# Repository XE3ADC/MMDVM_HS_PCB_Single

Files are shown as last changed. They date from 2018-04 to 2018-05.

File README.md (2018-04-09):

# MMDVM_HS_PCB_Single
Single Sided PCB for MMDVM Hotspot with RF7021SE module and Blue Pill STM32DUINO

This project provides a simple, singled sided PCB for the [MMDVM_HS Hotspot main repo](https://github.com/juribeparada/MMDVM_HS). 
Can be easily made using toner transfer, has very few wires. Just order the components (RF7021SE from Aliexpress and Blue Pill 
STM32DUINO clone) and put on board. Do not forget to replace the RF7021SE standard oscillator with a supported TCXO.

Licensed under CC-BY-SA 3.0

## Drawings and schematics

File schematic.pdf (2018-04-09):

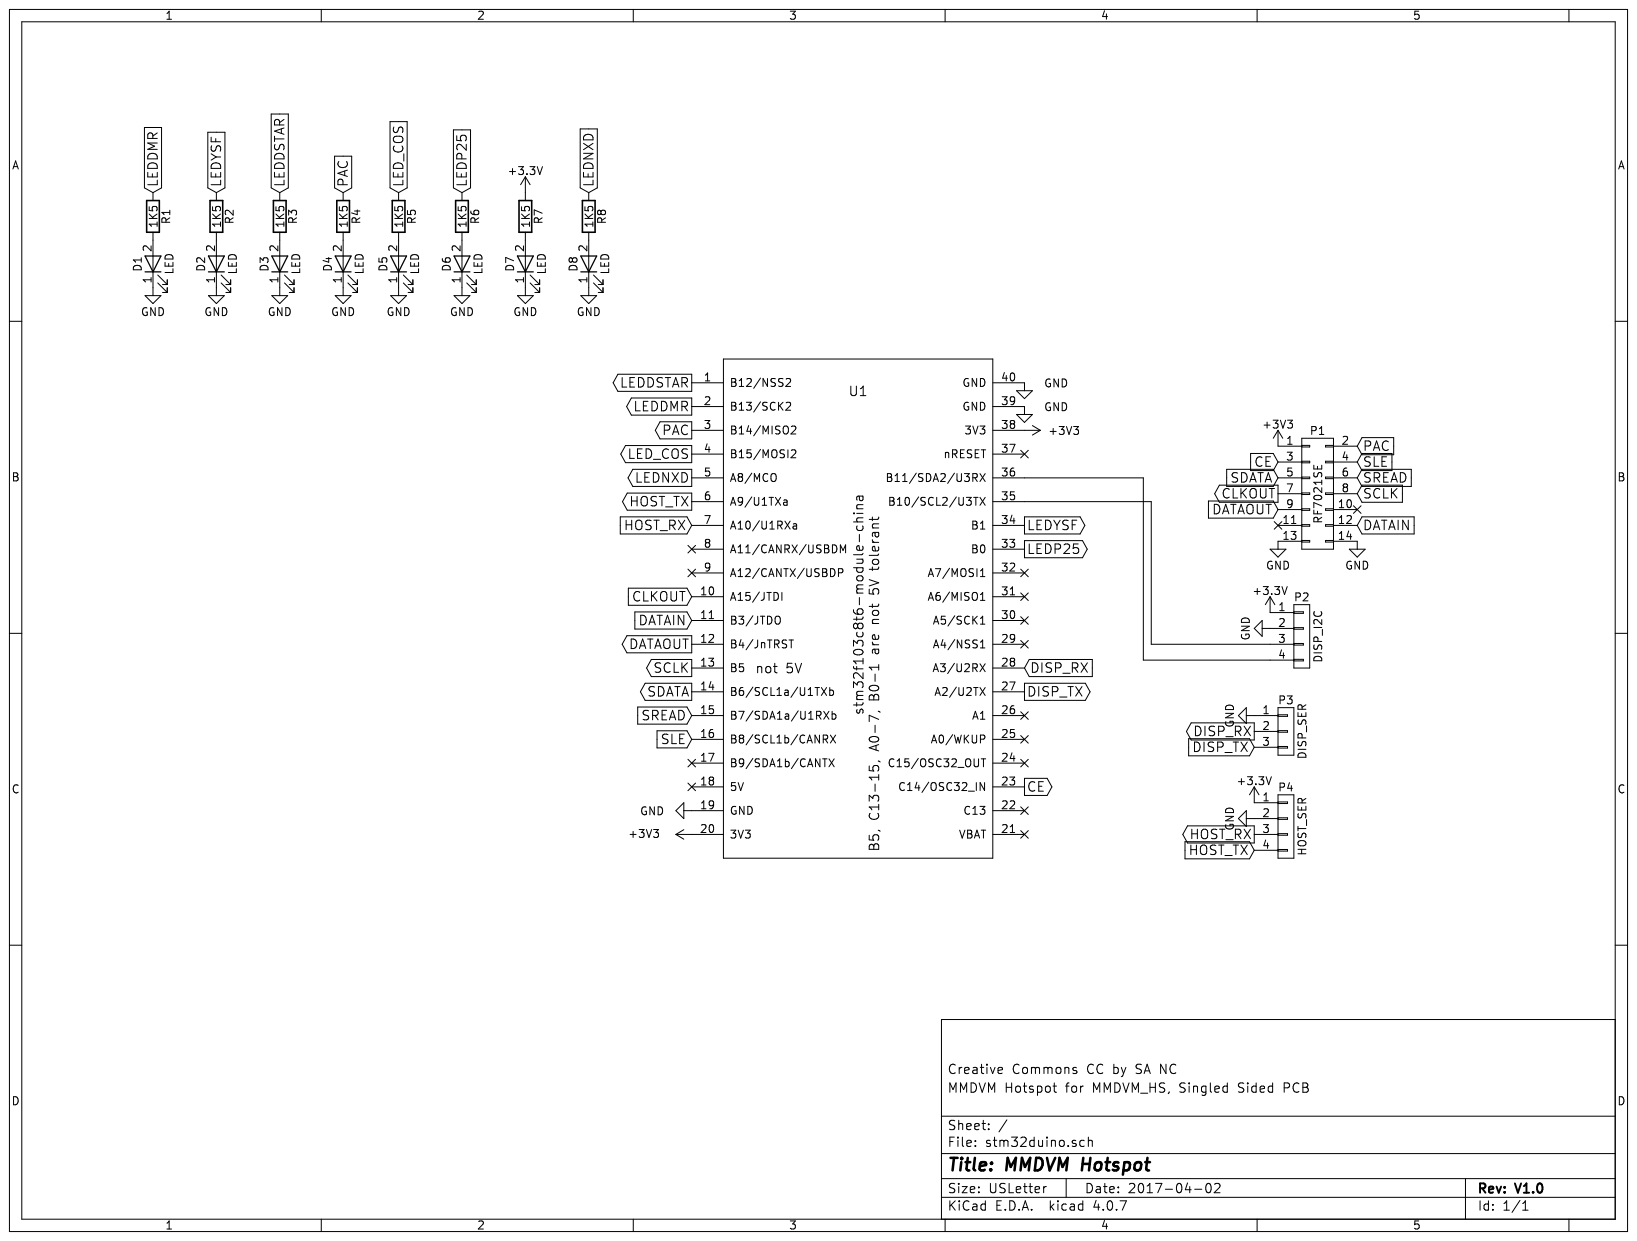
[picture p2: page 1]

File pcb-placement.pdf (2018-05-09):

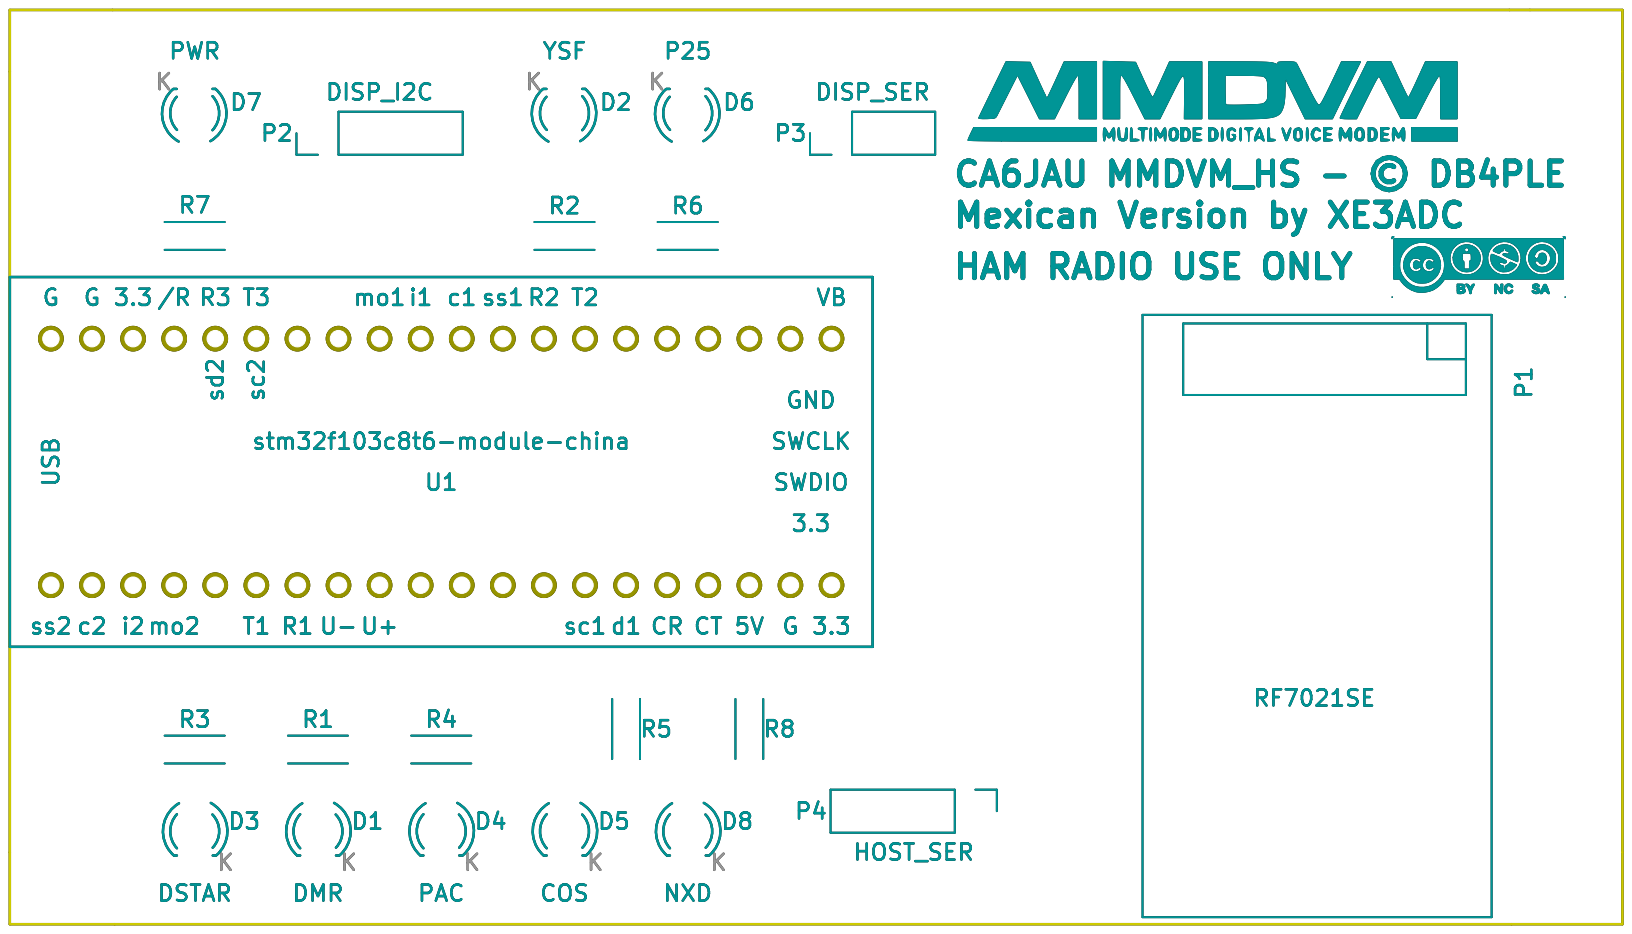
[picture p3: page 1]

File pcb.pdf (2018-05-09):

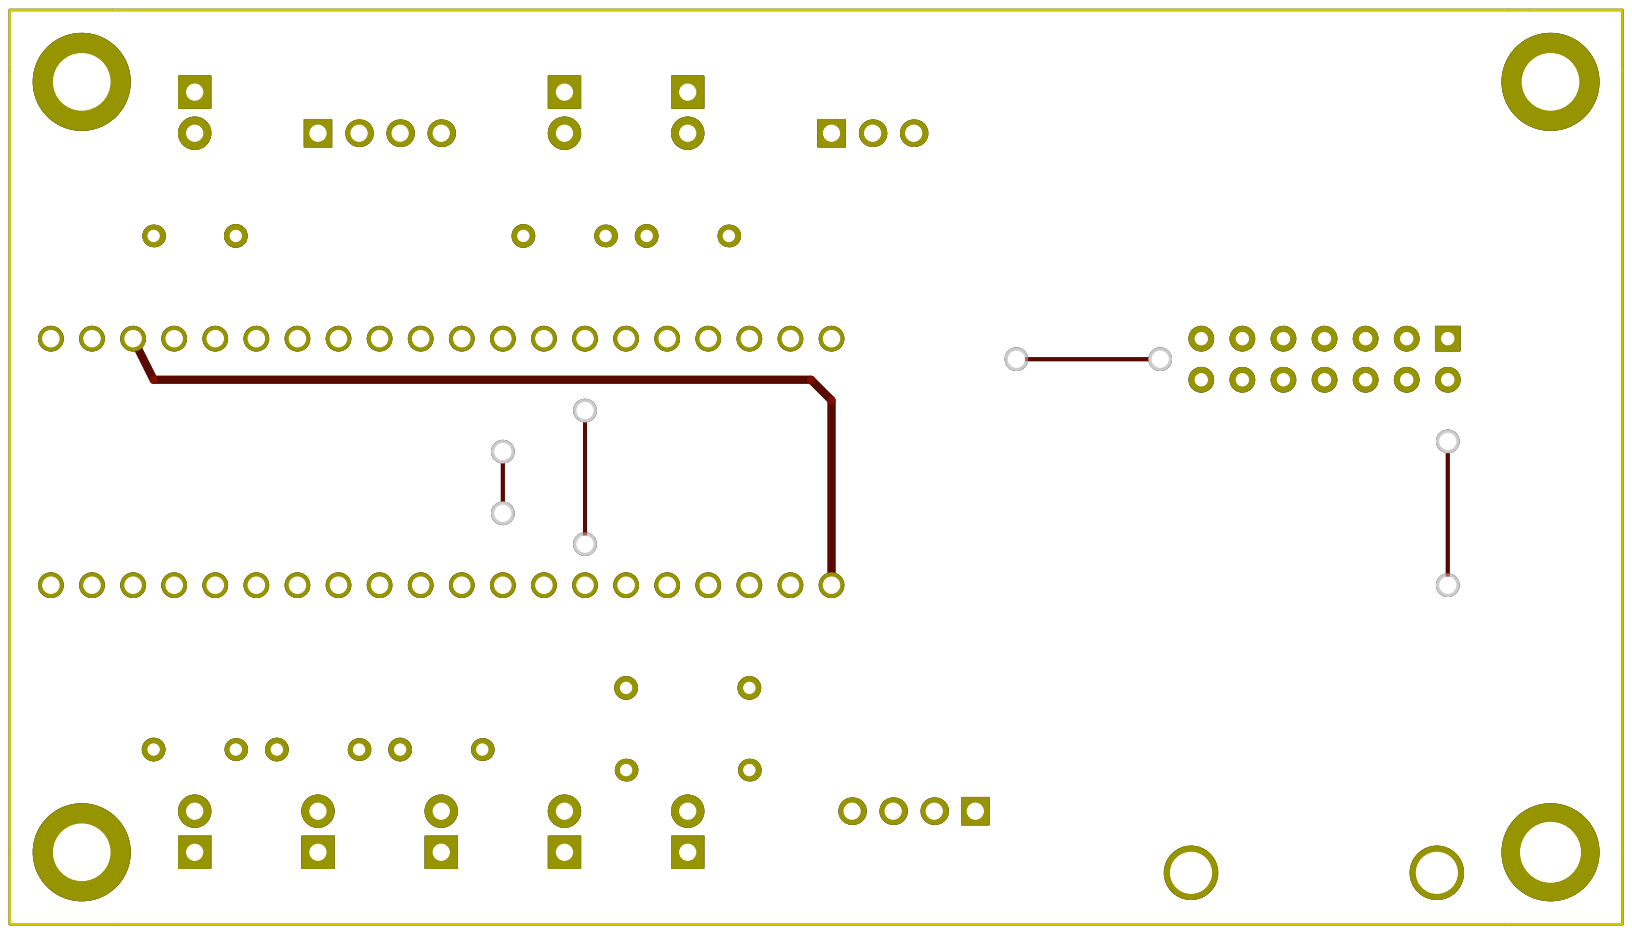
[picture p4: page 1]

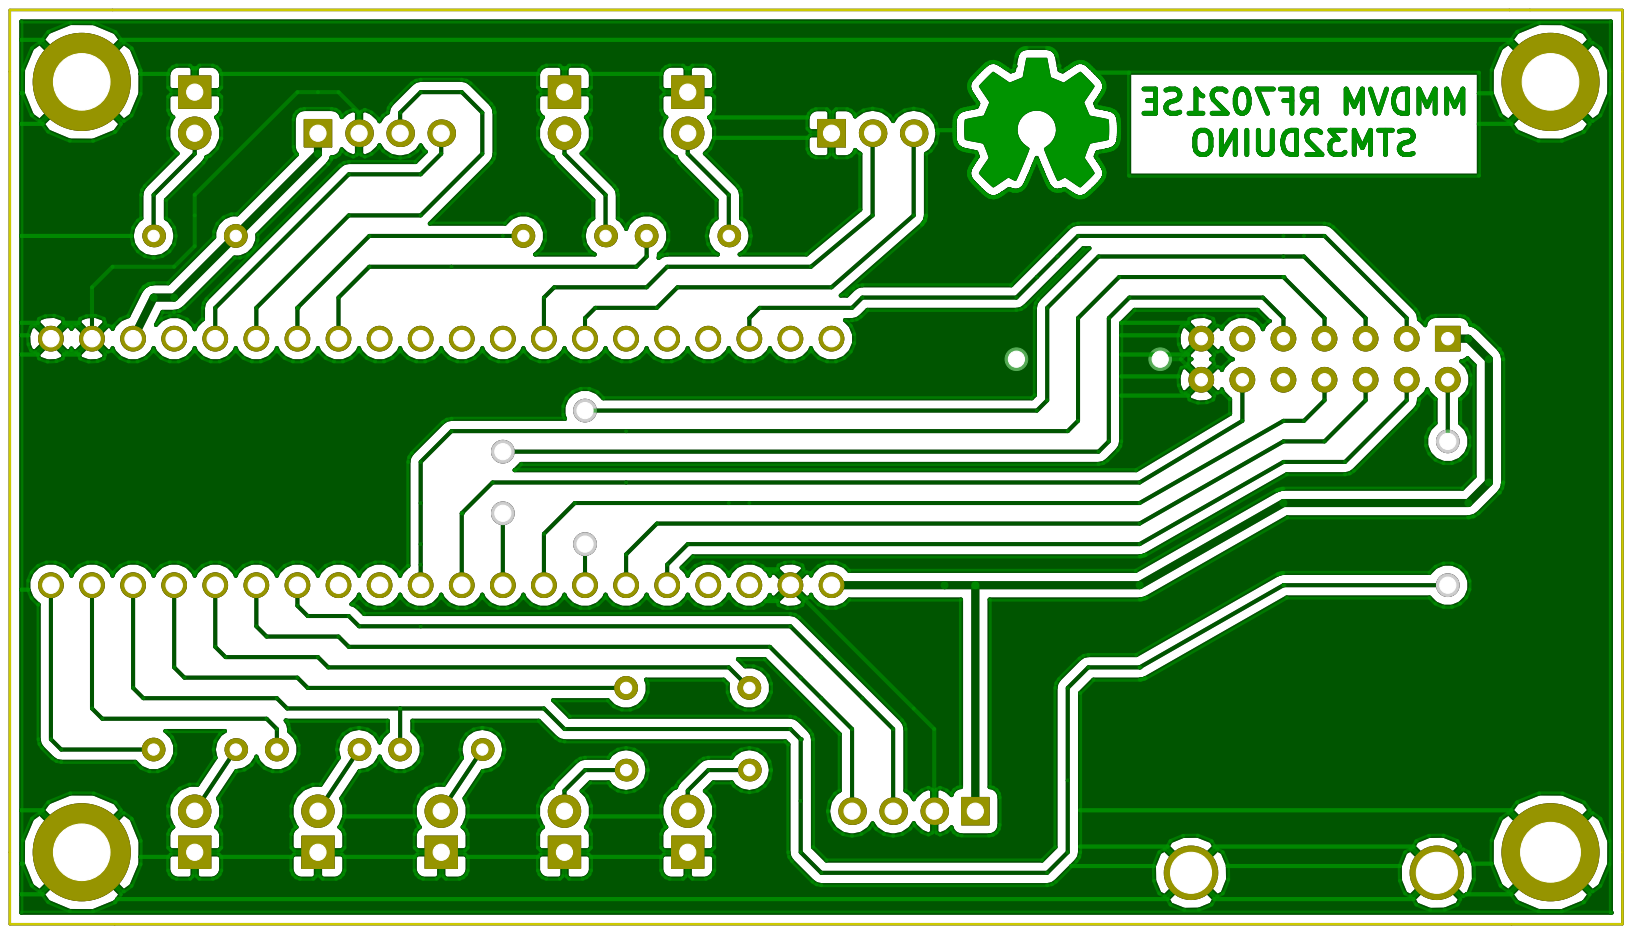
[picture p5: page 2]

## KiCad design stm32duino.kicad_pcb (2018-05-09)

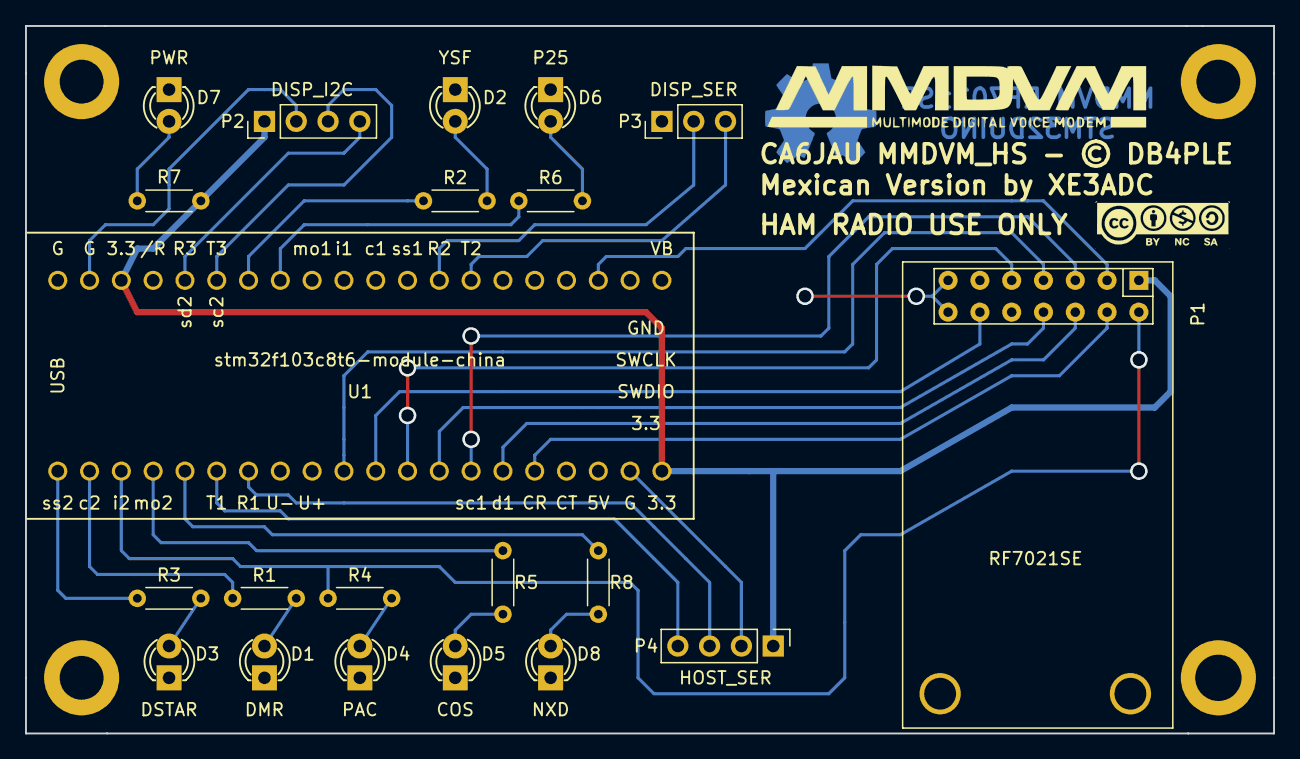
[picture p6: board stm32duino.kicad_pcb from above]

Board: 2 copper layers, 99.7 x 56.5 mm, 25 parts (0 on the bottom side), 31 nets.

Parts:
D1: DMR; LED-3MM
D2: YSF; LED-3MM
D3: DSTAR; LED-3MM
D4: PAC; LED-3MM
D5: COS; LED-3MM
D6: P25; LED-3MM
D7: PWR; LED-3MM
D8: NXD; LED-3MM
MH1, MH2, MH3: D=3.5mm; MountingHole_3.5mm_Pad
MH4: D=3.5mm; MountingHole_3.7mm_Pad
P1: RF7021SE; RF7021SE_Breakout
P2: DISP_I2C; Pin_Header_Straight_1x04_Pitch2.54mm
P3: DISP_SER; Pin_Header_Straight_1x03_Pitch2.54mm
P4: HOST_SER; Pin_Header_Straight_1x04_Pitch2.54mm
R1, R2, R3, R4, R5, R6, R7, R8: 1K5; R_Axial_DIN0204_L3.6mm_D1.6mm_P5.08mm_Horizontal
U1: stm32f103c8t6-module-china

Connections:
+3V3: P1.1, P2.1, P4.1, R7.1, U1.20, U1.38
CE: P1.3, U1.23
CLKOUT: P1.7, U1.10
DATAIN: P1.12, U1.11
DATAOUT: P1.9, U1.12
DISP_RX: P3.2, U1.28
DISP_TX: P3.3, U1.27
GND: D1.1, D2.1, D3.1, D4.1, D5.1, D6.1, D7.1, D8.1, MH1.1, MH2.2, MH3.3, MH4.4, P1.13, P1.14, P2.2, P3.1, P4.2, U1.19, U1.39, U1.40
HOST_RX: P4.3, U1.7
HOST_TX: P4.4, U1.6
LEDDMR: R1.1, U1.2
LEDDSTAR: R3.1, U1.1
LEDNXD: R8.1, U1.5
LEDP25: R6.1, U1.33
LEDYSF: R2.1, U1.34
LED_COS: R5.1, U1.4
unnamed: D1.2, R1.2
unnamed: D2.2, R2.2
unnamed: D3.2, R3.2
unnamed: D4.2, R4.2
unnamed: D5.2, R5.2
unnamed: D6.2, R6.2
unnamed: D7.2, R7.2
unnamed: D8.2, R8.2
unnamed: P2.3, U1.35
unnamed: P2.4, U1.36
PAC: P1.2, R4.1, U1.3
SCLK: P1.8, U1.13
SDATA: P1.5, U1.14
SLE: P1.4, U1.16
SREAD: P1.6, U1.15

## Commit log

2018-04-09 modified for Trhuhole components, added NXD LED.
    Modifications from original Project:
    -Changed LEDs and resistors from SMD to TrhuHole, and facing to the front of the board.
    -Added LED for NXD operation.
    -Increased track width for RF7021SE +3.3 VDC.
    -Modified header connectors orientation for 3D view.
    [stm32duino.dsn, stm32duino.kicad_pcb, stm32duino.sch]
2018-04-09 Updated Schematic with NXD LED
    Printed to PDF file from modified original project schematic, Added a LED and associated resistor D8 and R8.
2018-04-09 Produced PCB Placement PDF.
    Printed as PDF from Kicad
2018-04-09 Produced PCB layout as PDF
    Printed as PDF from KIcad
2018-04-09 Produced PCB layout as PDF
    Kicad back up file from last session
2018-05-09 Added Mounting holes and RF7021 breakout board footprint
    Additions: 3.5mm mounting holes on corners., footprint for RF7021 breakout board, Text labels for CC licensing, model, usage and credits, text labels for LED indicator signals.
    [stm32duino.kicad_pcb, stm32duino.sch]
2018-05-09 Produced updated PDF files.
    Produced PDF files for: PCB layout and component placement.

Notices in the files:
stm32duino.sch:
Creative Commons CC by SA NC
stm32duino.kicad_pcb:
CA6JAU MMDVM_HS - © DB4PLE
